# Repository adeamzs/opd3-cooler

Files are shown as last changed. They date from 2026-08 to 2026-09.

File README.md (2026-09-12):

# 
This is a clip on cooler for a oneplus pad 3. It is used for cooling of the SoC (cpu,gpu,ram..) so that when you do heavy tasks like in my case emulating pc games,youre able to push higher clock speeds and have better temperatures,which increase the lifespan of the SoC.

The 3d print has a mount for a fan,meshes for airflow. The top mesh is made so you can slide it out and in or replace it. On the right side is a case for electronics,which also opens by a sliding mechanism.

The fan can be oriented to either pull or push air.Either way, the air will go over the finstack. Pull is better for ergonomics while push is better for performance,altho the gains are rather small.

Onshape link:(https://cad.onshape.com/documents/3c457f388071a08e12b4f252/w/4df4de291808be73e0b4c8cf/e/eba3a5be513545a979cfcae8)





7691c172-e6ad-4b02-9b94-0bacc049cae3_with_skin

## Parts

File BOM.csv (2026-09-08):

Item | Description / Purpose | Shop | Price | USD | Link | Qty
Copper sheet | To transfer/spread heat | Allegro | €4.67 | $5.42 | https://allegro.sk/vyhladavanie?string=meden%C3%BD+plech+100x100x1%2C5 | 1
Fan | To cool everything | Alza | €8.89 | $10.31 | https://www.alza.sk/ARCTIC-P9-Max.htm | 1
Thermal pad | To transfer heat from tablet to copper sheet and from sheet to finstack | Alza | €7.99 | $9.27 | https://www.alza.sk/ | 1
PWM fan controller | To control the 12 V fan and supply it from the 12 V rail | Techfun | €4.90 | $5.68 | https://techfun.sk/produkt/kontroler-riadenia-ventilatora-pwm-12v-3-kanaly-hw-585/ | 1
MT3608 | To step the 18650 voltage up to 12 V | Techfun | €0.85 | $0.99 | https://techfun.sk/produkt/step-up-menic-mt3608/ | 1
18650 | To power everything | Techfun | €5.80 | $6.73 | https://techfun.sk/produkt/18650-li-ion-bateria-10c-high-discharge-rozne-typy/ | 1
TP4056 USB-C | To charge the 18650 | Techfun | €0.90 | $1.04 | https://techfun.sk/produkt/nabijaci-modul-pre-litiove-baterie-tp4056-ochranny-obvod-rozne-typy/ | 1
Heatsink 40×40×11 mm | The finstack the fan blows on | Techfun | €0.65 | $0.75 | https://techfun.sk/ | 1
JST 1.25 2P cable | Disconnectable power connections | Techfun | €0.15 | $0.17 | https://techfun.sk/ | 2
18650 holder | To hold the removable 18650 | Techfun | €0.70 | $0.81 | https://techfun.sk/ | 1
Button | To turn the fan on and off | Techfun | €0.15 | $0.17 | https://techfun.sk/produkt/tlacidlo-6-pin-dpdt-uzamykatelne/ | 1
M3 Heat inserts | To be able to mount the fan | — | €0 | $0 | Have at home | 4
M3 screws | To screw in the fan | — | €0 | $0 | Have at home | 4
Total |  |  | €34.65 | $40.19

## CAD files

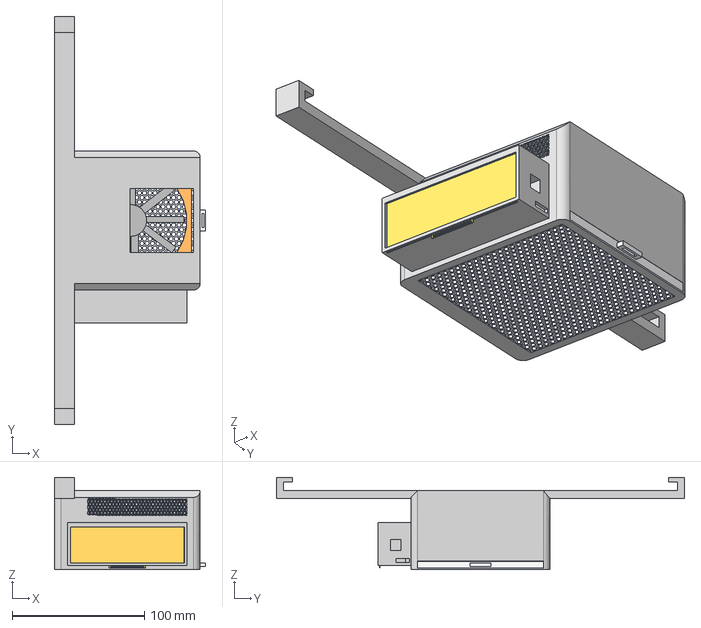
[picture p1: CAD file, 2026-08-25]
tablet-cooler-finalx3.step
114.0 x 308.0 x 69.5 mm

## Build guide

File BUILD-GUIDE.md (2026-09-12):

*Build Guide*

What you need:BOM parts,printed model,double sided tape,2 second glue,heat shrink.

*Electrical*

To build this you will need:BOM parts,printed model,double sided tape,2 second glue,heat shrink
first,solder the JST connectors (tp4056 b- , b+ fe/male) then on the 18650 holder cut a part of wire (for mt3608 to pwm regulator)
then solder jst on the reamining wire of holder(- and + fe/male depends on tp4056 type) . Solder jst (fe/male) on tp4056 out+ ,out- , cut the wire + part of the wire in half and solder on a button.Then resolder the jst connector on the other end.Solder on middle and any other pin.Ground is only one not cut. and on the mt3608 vin+ , vin- (fe/male depends on tps out)
then get the cable from the 18650 holder and solder it to mts vout+ , vout-. Dont forget to put heat shrink on the cables!

*Mechanical*

cut the 100x100 copper sheet into 50x50mm (or if you can buy a cut 50X50 sheet),glue it into the hole inside of the fan chamber.
put one sheet of the thernal pad onto the bottom and top. on the top,put the heatsink on it and if you want cut around it.
cut the thermal pad into four 50x50 sheets.
use double sided tape to keep electronics in place and use friction fit/glue the button, inside the electronics compartment.
Use soldering iron to fit in the heat inserts.
then,orient the fan so its PWM connector is in immediate proximity to the hole between fan chamber and electronics compartment,so you can route the pwm cable inside the compartment.
screw in the fan,plug in all the jsts .Now you will need to configure settings on the pwm controller.The controller comes with a thermistor and piezo buzzer.
Use these if you like,but thermistor isnt gonna work properly for the temperature based pwm control of the board because you cant put it close to the hotspot.
switch the first switch of the board, (DIP 1) on and connect the fan to FAN1 on the pwm board. This mode outputs 40% PWM which is perfect for the p9 max for:
zero sound,good efficiency,and strong performance.
If you do want higher speeds, connect to FAN2 or FAN3 and turn the dials next to them for higher pwm %.

# Wiring Diagram

7691c172-e6ad-4b02-9b94-0bacc049cae3_with_skin

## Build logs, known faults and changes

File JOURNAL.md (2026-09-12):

---
title: "opd3-cooler"
github: "adeamzs/opd3-cooler"
description: "A clip on cooler for the oneplus pad 3"
created_at: "2026-08-18"
---

# August 18th: Clip on cad model

I started making the CAD model for the clip on part of the project.
I had some issues with Onshape,and how to start but i figured it out on my own.





*Total time spent:1.5h*

# August 19th:Prototyping,Cad and Research

I made multiple iterations of the clip on until it fit unto my tablet.Afterwards i went to look at what parts id use,cause they would decide how i make the chassis in cad.After making the chassis,i needed to make a mesh.I was trying all tools for 20 mins but then i stumbled onto onshape search and found a community made tool to make meshes.I was saved! Its named grid extrude.Afterwards i had to make a cut-out for my copper sheet,so i made a lip-style cutout,where the plate would be glued. Then i started making mounts for a 92x92mm fan,but ive set it aside for tmrw.My brain was like on overdrive while making the model,cause ive never seen cad before in my life.









0-02-05-9425e5e6087ca703652d303e0ebee4aec1cf51b96bcc39fce5afede28ed931f9_224c4ae182f





*Total time spent:6h*

# August 20th:Finishing

I finished the fan mounting holes,made the side case for electronics.Now i needed a way to open the case,and open the cooling part. I originally wanted to make a print in place hinge,but i made a slide in door for the case and a slide in mesh for the cooling area,so i could open the device up,fix and or upgrade components.I made my Bill Of Materials,but i had a really hard time doing so,because aliexpress has large duties (thnx EU).So i had to look at local stores for the parts i needed,which took some time finding but i found them in the end.







*Total time spent:5h*

# August 24th:Polishing

I made aesthetic changes to my model (fillets,so rounded some corners so it is less blocky) , modeled the fan,not great but for demonstration and rechecked tolerances for the slide in mechanisms.I updated my BOM to have better shipping costs, but i had to give up the IP2312 for a TP4056 because it was the only viable option.



*Total time spent:3h*

# August 25th:Button

I realized today that i forgot to add a button to turn the fan on and off.I went to my printer room and grabbed a button, i have lots of at home and took measurements of it.I afterwards made a hole in my model for it,im expecting it to be a friction fit,if not ill glue it in.I also made a build guide for the project.



viber_image_2026-08-25_15-27-55-494

*Total time spent:1.5h*

# September 8th:Update bom to csv and readme.

I updated my bom from markdown format to csv format and added a "why make this" kinda section to the readme.

200b2d2d-9398-4acc-adab-504b1dde0898_thumb

*Total time spent:0.5h*

# September 12th:Wiring Diagram

Made a wiring diagram,had to look up all the terminals and connectors of the parts. Find it in build-guide.md

7691c172-e6ad-4b02-9b94-0bacc049cae3_with_skin

*Total time spent:0.5h*

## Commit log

2026-08-19 Add journal entry for CAD model development
    Documented initial progress on CAD model for clip-on cooler.
2026-08-19 Update JOURNAL.md with August 19th entry
    Documented prototyping process, CAD modeling, and challenges faced while designing chassis and mounts.
2026-08-20 Add files via upload
    the model for the clip on cooler!
    [opd3-cooler-final.step]
2026-08-20 Update JOURNAL.md with August 20th entry
    Documented progress on fan mounting and case design, including challenges with sourcing materials.
2026-08-24 Add files via upload
    THE final final step ( a butchered fan looking thing is there for demonstration dont print that)
    [tablet-cooler-final-final.step]
2026-08-24 Polish model and update BOM for shipping costs
    Updated journal entry for August 24th with aesthetic changes and BOM updates.
2026-08-25 Add build guide for electrical and mechanical assembly
    Added detailed instructions for electrical and mechanical assembly of the device, including parts needed and configuration settings.
2026-08-25 Document updates for August 25th and aesthetic changes
    Added details about button integration and updated aesthetic changes.
2026-08-25 Add button entry to BOM and fix formatting
2026-08-25 Correct button link formatting in BOM.md
    Fixed link formatting for the button entry in BOM.md.
2026-08-25 Enhance build guide with additional materials and details
    Updated the build guide to include heat shrink in the materials list and clarified the electrical assembly instructions.
2026-08-25 Add files via upload
    really the final final final model. dont print the butchered fan tho,remove that in the slicer. (its two parts)
    [tablet-cooler-finalx3.step]
2026-08-26 Update BUILD-GUIDE with thermal pad and fan details
    Added instructions for thermal pad placement and fan orientation.
2026-08-30 Add M3 heat inserts and screws to BOM
    Added M3 heat inserts and screws to the BOM with quantities.
2026-08-30 Add soldering iron instructions to fan assembly guide
    Added instructions for using a soldering iron to fit heat inserts in the fan assembly process.
2026-09-08 Revise README for clarity and additional resources
    Updated the README to provide a clearer explanation of the clip-on cooler's purpose and functionality, including details about the fan orientation and airflow. Added Onshape link and images.
2026-09-08 Add BOM.csv with component details and pricing
    BOM for opening in excel and stuff
    [BOM.csv]
2026-09-12 Add wiring diagram to BUILD-GUIDE.md
    Added a wiring diagram image to the build guide.
2026-09-12 Document wiring diagram creation in JOURNAL.md
    Added a wiring diagram section with time spent.
2026-09-12 Update BOM format and enhance README
    Converted BOM from markdown to CSV format and added a rationale section to the README.
